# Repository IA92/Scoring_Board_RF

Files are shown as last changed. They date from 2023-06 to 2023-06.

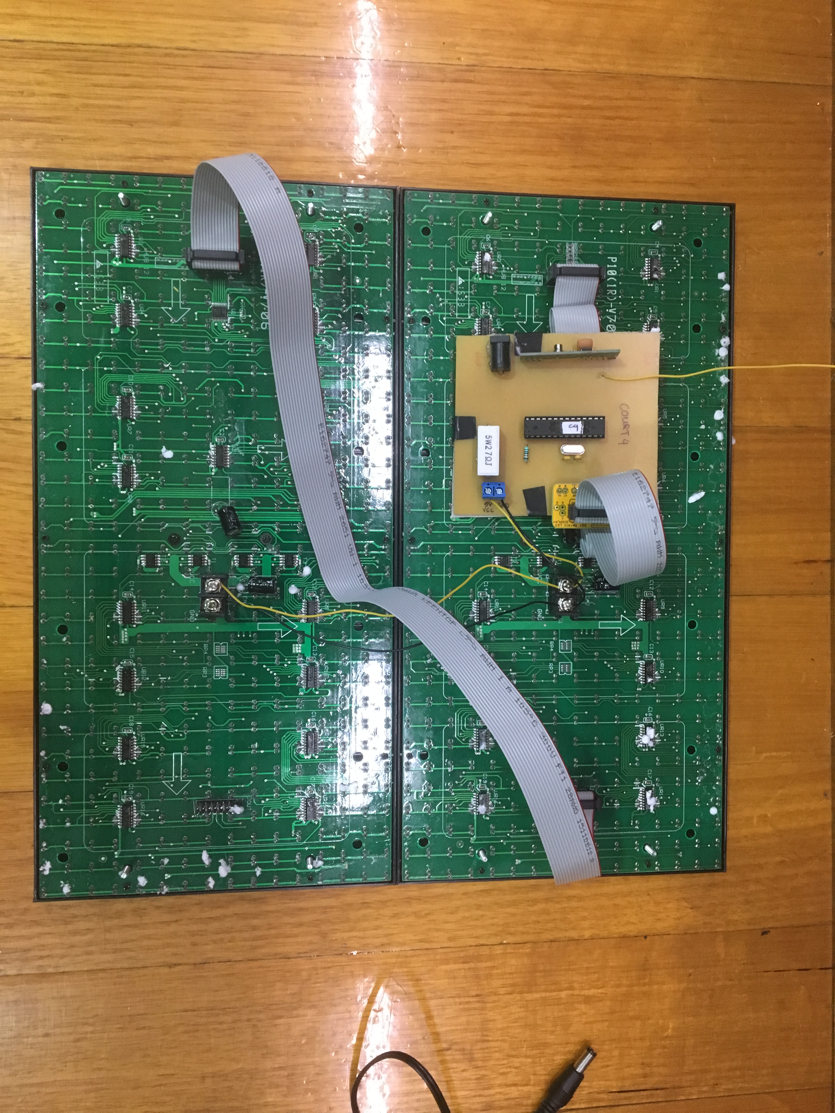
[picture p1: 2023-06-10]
photos/IMG_0790.JPG

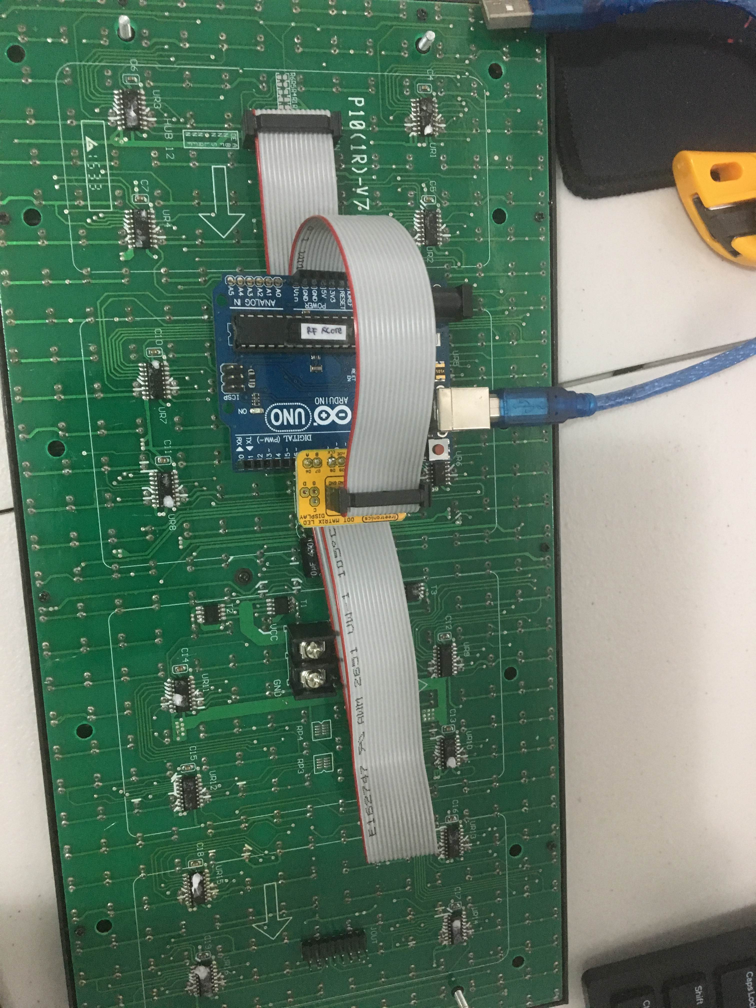
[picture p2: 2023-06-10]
photos/IMG_0505.JPG

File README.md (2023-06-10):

# Scoring_Board_RF
An archive of old scoring board project for badminton games.
Note: Code are not well written and managed. Instructions are not fully accurate.

Link to project video: https://youtu.be/4vFphWg7GTI

## Version of arduino files
- scoringBoard.ino: Testing LED panel
- scoringIR.ino, scoringIR_1 and scoringIR_2: 1 LED panel with IR instructions
- HunterBadminton_ProjectRF: 1 LED panel with RF instructions
- HunterBadminton_ProjectRF_Larger: 2 LED panel with RF instructions

## Getting Started with the Project RF Version
### Keyfob
- Get 433MHz key fobs from ebay.
- Use a 433MHz transmitter to transmit the desired code to be cloned by the key fob
- Set the key fob to be in programming mode and clone the transmitted code for each button. 
  - Reference video: https://www.youtube.com/watch?v=l-k_XvkZ0jE
### Code
- Ensure that `buttonCodes` array corresponds to the programmed instructions of the 4 buttons in the key fob

## References for the code in the libraries
- Freetronics lib https://github.com/freetronics/DMD/blob/master/DMD.cpp
- TimerOne lib http://code.google.com/p/arduino-timerone/downloads/list
- RF lib https://github.com/sui77/rc-switch/blob/master/RCSwitch.h

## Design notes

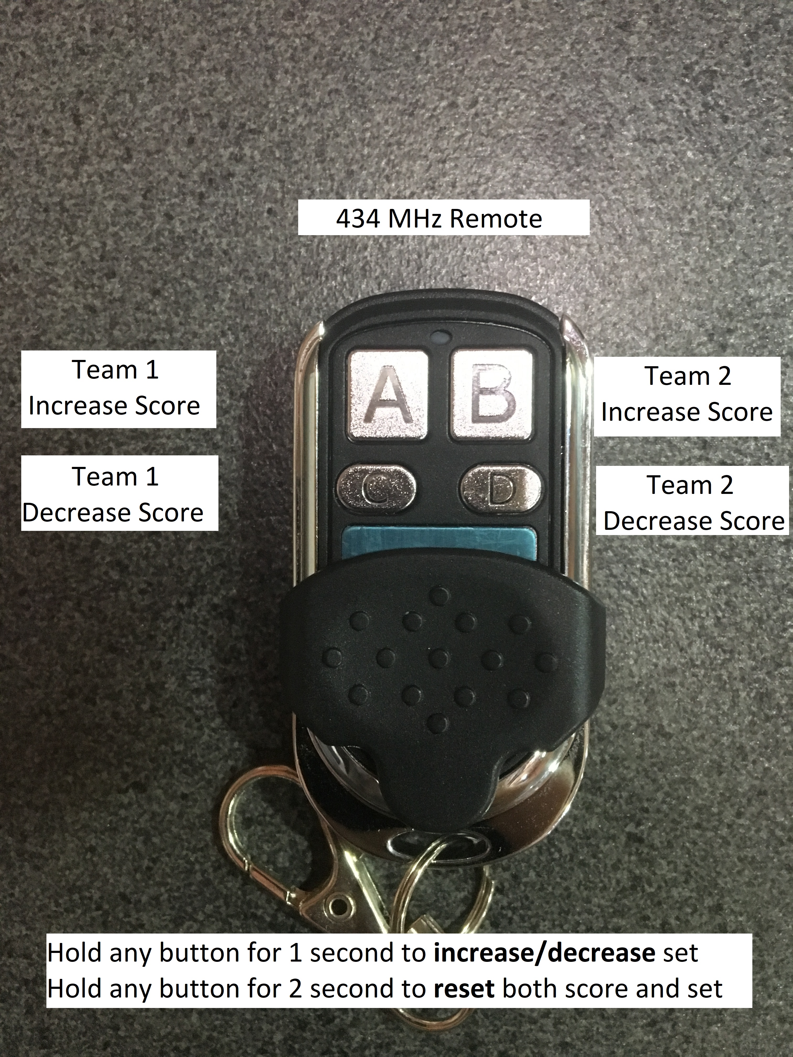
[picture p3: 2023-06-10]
photos/IMG_0797_Editted.JPG

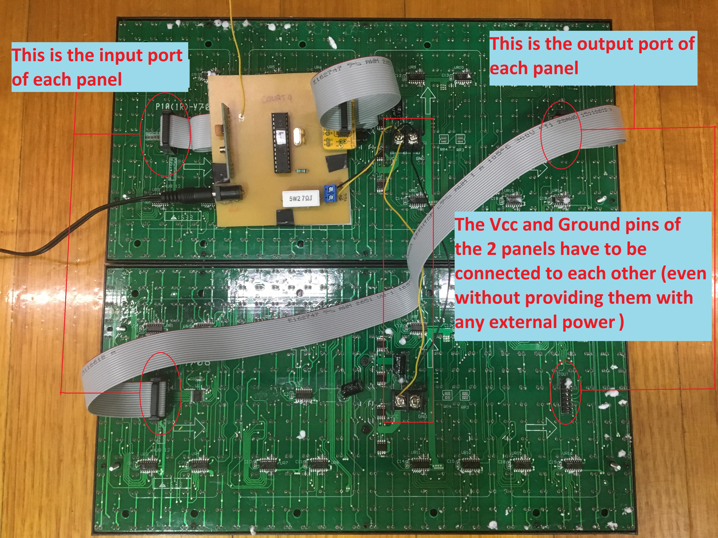
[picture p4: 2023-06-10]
photos/IMG_0792_editted.jpg

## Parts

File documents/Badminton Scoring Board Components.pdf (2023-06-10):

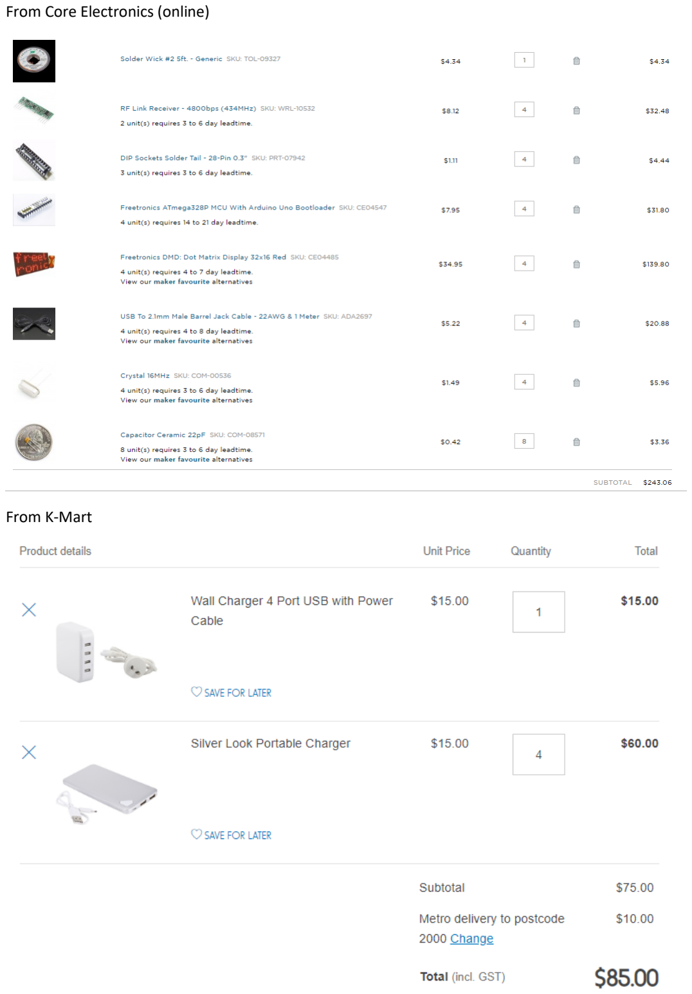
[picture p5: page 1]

From Core Electronics (online)

From K-Mart

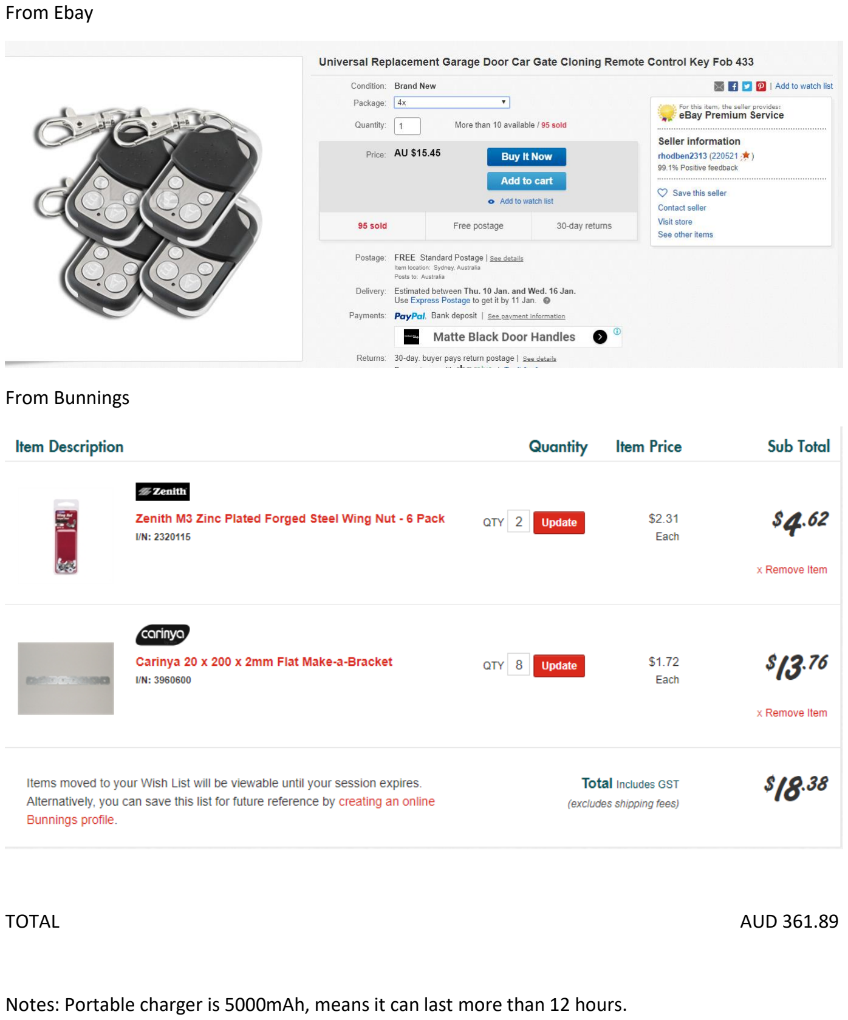
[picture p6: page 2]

From Ebay

From Bunnings

TOTAL | AUD 361.89

Notes: Portable charger is 5000mAh, means it can last more than 12 hours.

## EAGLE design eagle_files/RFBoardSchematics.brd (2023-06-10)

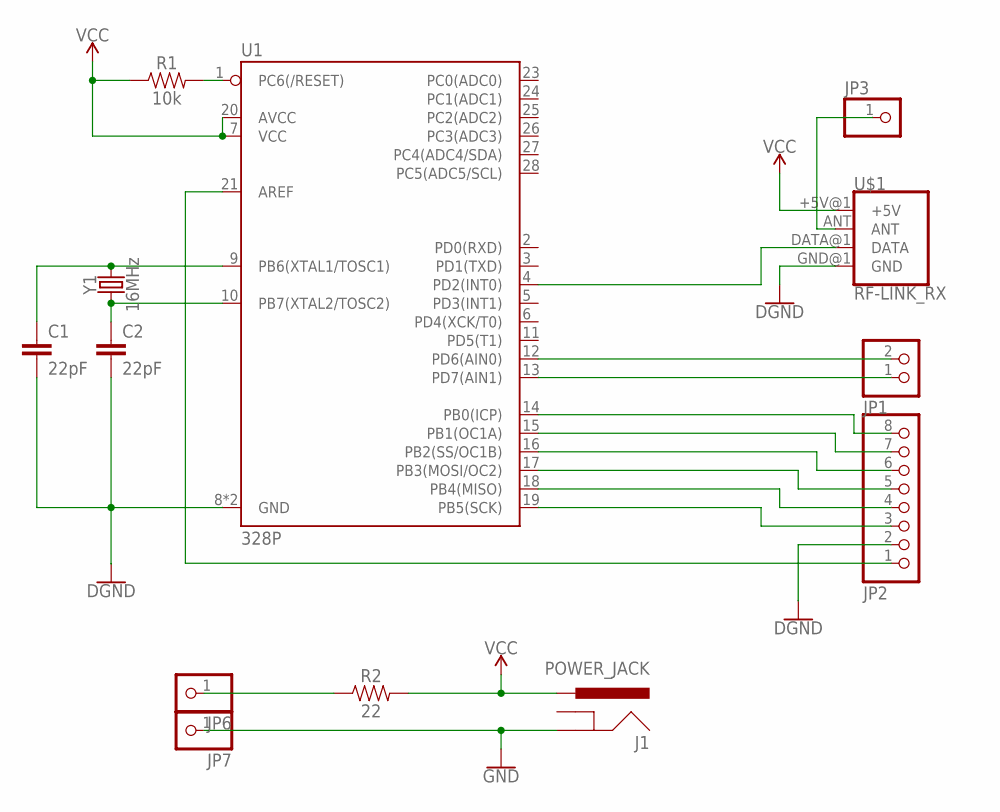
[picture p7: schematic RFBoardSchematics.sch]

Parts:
C1, C2: 22pF; CAP-PTH-2.54
J1: POWER_JACK; POWER_JACK_PTH
JP1: PINHD-1X2; 1X02
JP2: PINHD-1X8; 1X08
JP3, JP6, JP7: PINHD-1X1; 1X01
R1: 10k; AXIAL-0.3
R2: 22; AXIAL-0.3
U1: 328P; DIP28
U$1: RF-LINK_RX
Y1: 16MHz; HC49US

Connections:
GND: C1.2, C2.2, J1.GND, JP2.2, JP7.1, U1.8 (GND), U1.22 (GND), U$1.GND@1 (GND)
unnamed: R1.P$2 (2), U1.1 (PC6(/RESET))
unnamed: C1.1, U1.9 (PB6(XTAL1/TOSC1)), Y1.2
unnamed: C2.1, U1.10 (PB7(XTAL2/TOSC2)), Y1.1
unnamed: JP6.1, R2.P$1 (1)
unnamed: JP3.1, U$1.ANT
unnamed: U1.4 (PD2(INT0)), U$1.DATA@1 (DATA)
unnamed: JP1.2, U1.12 (PD6(AIN0))
unnamed: JP1.1, U1.13 (PD7(AIN1))
unnamed: JP2.8, U1.14 (PB0(ICP))
unnamed: JP2.7, U1.15 (PB1(OC1A))
unnamed: JP2.6, U1.16 (PB2(SS/OC1B))
unnamed: JP2.5, U1.17 (PB3(MOSI/OC2))
unnamed: JP2.4, U1.18 (PB4(MISO))
unnamed: JP2.3, U1.19 (PB5(SCK))
unnamed: JP2.1, U1.21 (AREF)
VCC: J1.PWR, R1.P$1 (1), R2.P$2 (2), U1.7 (VCC), U1.20 (AVCC), U$1.+5V@1 (+5V)

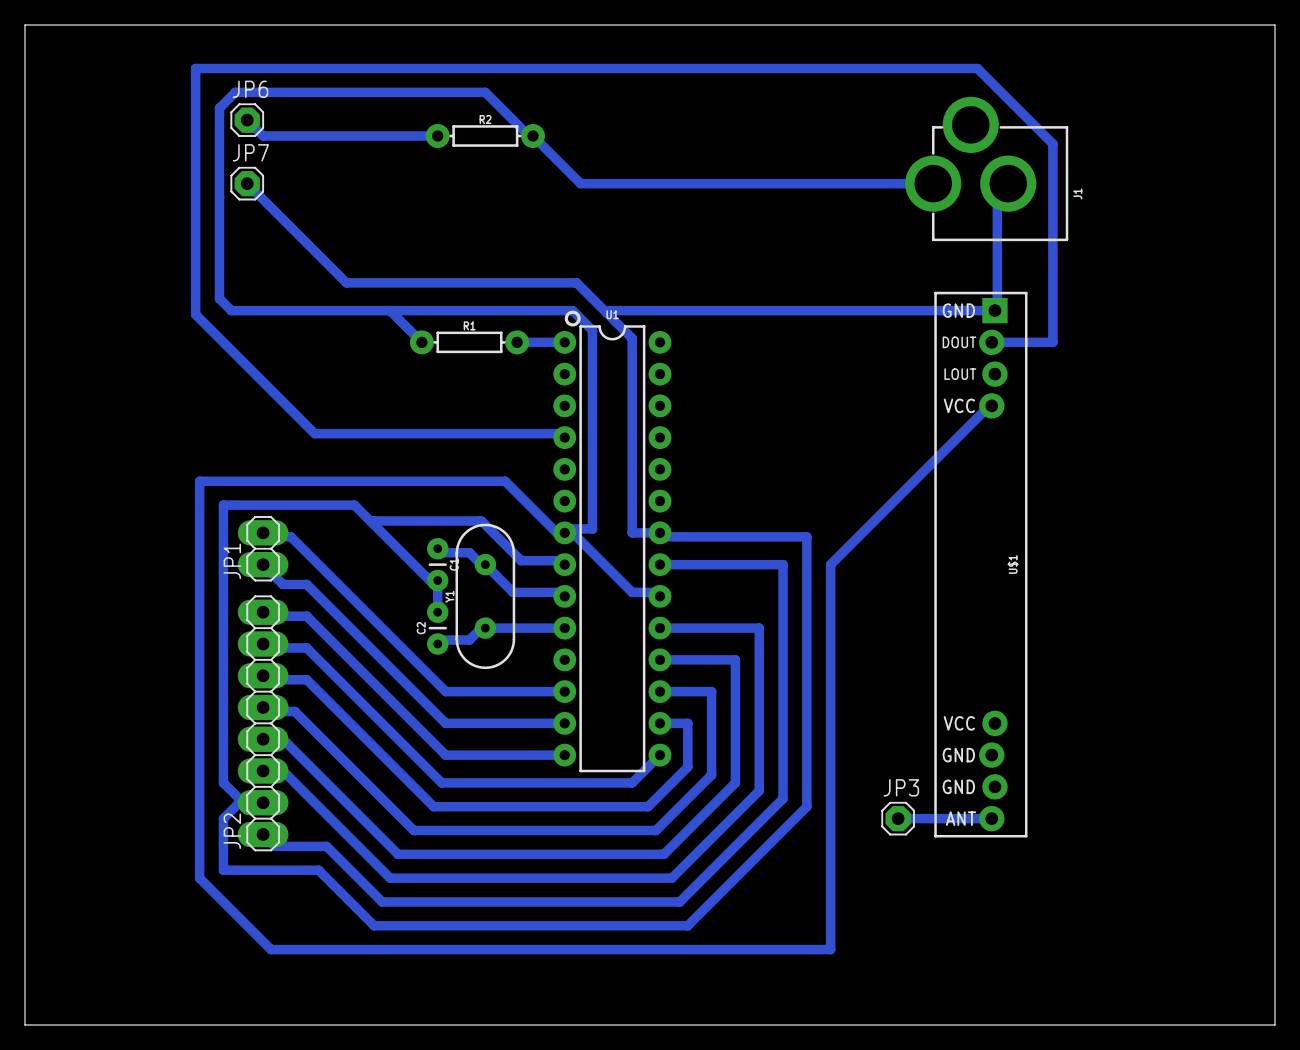
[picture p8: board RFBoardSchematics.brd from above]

Board: 2 copper layers, 100.0 x 80.0 mm, 13 parts (0 on the bottom side), 17 nets.

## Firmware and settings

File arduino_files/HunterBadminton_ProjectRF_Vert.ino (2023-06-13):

//Badminton Score Board with Team Serving
#include <SPI.h>        //SPI.h must be included as DMD is written by SPI (the IDE complains otherwise)
#include "DMD.h"        //
#include "TimerOne.h"   //
#include "SystemFont5x7.h"
#include "fixednums7x15.h"
#include "Arial_black_16.h"

#include "RCSwitch.h"

RCSwitch mySwitch = RCSwitch();

//Fire up the DMD library as dmd
#define DISPLAYS_ACROSS 1
#define DISPLAYS_DOWN 2
DMD dmd(DISPLAYS_ACROSS, DISPLAYS_DOWN);

int led=13;
String currentButton;
String secondButton;
String buttonCodes[]={"3001","3002","3003","3004"};
int countPress;
long int timePress;
int setA;char setAbuff[8];
int setB;char setBbuff[8];
char scoreA;char scoreAbuff[8];
char scoreB;char scoreBbuff[8];
int scoreX=17;
int scoreX_s=25;
int scoreYA=0;
int scoreYB=16;
int setX=12;
int setYA=3;
int setYB=19;
int serve;
bool toggle;
void ScanDMD()
{ 
  dmd.scanDisplayBySPI();
}
void clearPixels(int column_start, int column_end, int row_start, int row_end){
  for (int j=column_start;j<column_end;j++){   //Column
    for (int i=row_start;i<row_end;i++){  //Row
      dmd.writePixel(  j,i, GRAPHICS_NORMAL,0);
    }
  }
}
void drawServe(int Team){
  clearPixels(17, 32, 30, 32);
  clearPixels(17, 32, 14, 16);
  dmd.drawFilledBox(  17, (Team-1)*2+Team*14,31,(Team-1)*2+Team*14+1,GRAPHICS_NORMAL );
}

void drawSet(int setA, int setB){
  dmd.selectFont(SystemFont5x7);      
  if (setA==1) 
    dmd.drawChar(  setX,  setYA,  '1', GRAPHICS_NORMAL );
  else
    clearPixels(setX, scoreX, setYA, 14);
    
  if (setB==1) 
    dmd.drawChar(  setX,  setYB,  '1', GRAPHICS_NORMAL );
  else
    clearPixels(setX, scoreX, setYB, 28);
}

void drawScore(int8_t scoreAtemp, int8_t scoreBtemp){
  dmd.selectFont(fixednums7x15);
  if (scoreAtemp<10){
    dmd.drawString(  scoreX,  scoreYA, "0", 2, GRAPHICS_NORMAL );
    dmd.drawString(  scoreX_s,  scoreYA, itoa (scoreAtemp, scoreAbuff, 10), 2, GRAPHICS_NORMAL );
  } else{
    dmd.drawString(  scoreX,  scoreYA, itoa (scoreAtemp, scoreAbuff, 10), 2, GRAPHICS_NORMAL );
  }
  
  if (scoreBtemp<10){
    dmd.drawString(  scoreX, scoreYB, "0", 2, GRAPHICS_NORMAL );
    dmd.drawString(  scoreX_s, scoreYB, itoa (scoreBtemp, scoreBbuff, 10), 2, GRAPHICS_NORMAL );
  } else{
    dmd.drawString(  scoreX, scoreYB, itoa (scoreBtemp, scoreBbuff, 10), 2, GRAPHICS_NORMAL );
  }
}

void setup() {
  Serial.begin(9600);
  mySwitch.enableReceive(0); 
  delay(2000); while (!Serial); //delay for Leonardo
  pinMode(led, OUTPUT);
  Serial.println(F("Ready to receive RF signals"));
  
     //initialize TimerOne's interrupt/CPU usage used to scan and refresh the display
   Timer1.initialize( 5000 );           //period in microseconds to call ScanDMD. Anything longer than 5000 (5ms) and you can see flicker.
   Timer1.attachInterrupt( ScanDMD );   //attach the Timer1 interrupt to ScanDMD which goes to dmd.scanDisplayBySPI()
  
  // Initiating Variable
  setA=0;
  setB=0;
  scoreA=0;
  scoreB=0;
  serve=1;
  toggle=false;
  countPress=0;
  currentButton="1000";
  secondButton="1000";
  //clear/init the DMD pixels held in RAM
  dmd.clearScreen( true );   //true is normal (all pixels off), false is negative (all pixels on)
  //initializing
  dmd.selectFont(SystemFont5x7);   
  dmd.drawString(  0,  scoreYA,  "SE", 2, GRAPHICS_NORMAL );
  dmd.drawString(  0,  scoreYA+8,  "AT", 2, GRAPHICS_NORMAL );
  dmd.drawString(  0,  scoreYB,  "WA", 2, GRAPHICS_NORMAL );
  dmd.drawString(  0,  scoreYB+8,  "LL", 2, GRAPHICS_NORMAL );
  drawSet(setA, setB);
   drawScore(scoreA, scoreB);
//   dmd.drawFilledBox(17,14,31,15,GRAPHICS_NORMAL);
   drawServe(serve);
}
 
void loop() {

  byte b;
  //Continue looping until you get a complete signal received
  if (millis()-timePress>100){
      countPress=0;
    }
  if (mySwitch.available()) {
    secondButton=String(mySwitch.getReceivedValue());
    if (secondButton==currentButton && ((millis()-timePress)<100||countPress==1)){
      countPress=countPress+1;
      mySwitch.resetAvailable();
      Serial.println(currentButton);
      Serial.println(secondButton);
      if (countPress==5){
        if (currentButton==buttonCodes[3]){
          setB=setB-1;
          Serial.println("SetB-");
        }
        else if (currentButton==buttonCodes[1]){
          if (setA+setB<3) setB=setB+1;
          Serial.println("SetB+");
          serve=2;
          toggle=true;
        }
        else if (currentButton==buttonCodes[2]){
          setA=setA-1;
          Serial.println("SetA-");
        }
        else if (currentButton==buttonCodes[0]){
          if (setA+setB<3) setA=setA+1;
          Serial.println("SetA+");
          serve=1;
          toggle=false;
        }
        if (scoreA<0) scoreA=0;
        else if (scoreA>31) scoreA=31;
        if (scoreB<0) scoreB=0;
        else if (scoreB>31) scoreB=31;      
        if (setA<0) setA=0; 
        if (setA>2) setA=2;
        if (setB<0) setB=0; 
        if (setB>2) setB=2;
        drawScore(scoreA, scoreB);
        drawServe(serve);
        if (serve>2) {
          serve=1;
          drawServe(serve);
        } else if (serve<1){
          serve=2;
          drawServe(serve);
        }
        mySwitch.resetAvailable();
        drawSet(setA, setB);
      }
      else if (countPress==10){
        toggle = toggle? false : true;
        serve = serve + 1;
        int tempA = scoreA;
        scoreA=scoreB;
        scoreB=tempA;
        setA = 0;
        setB = 0;
        drawScore(scoreA, scoreB);
        drawServe(serve);
        if (serve>2) {
          serve=1;
          drawServe(serve);
        } else if (serve<1){
          serve=2;
          drawServe(serve);
        }
        mySwitch.resetAvailable();
        drawSet(setA, setB);
      }
      else if (countPress==20){
      Serial.println("in countpress>25");
//      if ((currentButton==buttonCodes[0] || currentButton==buttonCodes[1]) && (secondButton==buttonCodes[2] || secondButton==buttonCodes[3]) ){
        setA=0;
        setB=0;
        scoreA=0;
        scoreB=0;
        toggle=false;
        serve=1;
//      }
        if (scoreA<0) scoreA=0;
        else if (scoreA>31) scoreA=31;
        if (scoreB<0) scoreB=0;
        else if (scoreB>31) scoreB=31;      
        if (setA<0) setA=0; 
        if (setA>2) setA=2;
        if (setB<0) setB=0; 
        if (setB>2) setB=2;
        drawScore(scoreA, scoreB);
        drawServe(serve);
        if (serve>2) {
          serve=1;
          drawServe(serve);
        } else if (serve<1){
          serve=2;
          drawServe(serve);
        }
        countPress=0;
        mySwitch.resetAvailable();
        drawSet(setA, setB);
    }
    }
    
    
    else if (countPress<5){
      currentButton=secondButton;
      countPress=1;
      if (currentButton!=buttonCodes[9] && currentButton!="0"){
        
        if (currentButton==buttonCodes[0]){
          scoreA=scoreA+1;
          if (toggle){
            serve=serve+1;
//            drawServe(serve);
            toggle=false;
          }
          Serial.println("ScoreA+");
        }
        else if (currentButton==buttonCodes[2]){
          scoreA=scoreA-1;
          Serial.println("ScoreA-");
        }
        else if (currentButton==buttonCodes[1]){
          scoreB=scoreB+1;
          if (!toggle){
            serve=serve+1;
//            drawServe(serve);
            toggle=true;
          }
          Serial.println("scoreB+");
        }
        else if (currentButton==buttonCodes[3]){
          scoreB=scoreB-1;
          Serial.println("scoreB-");
        }
        if (scoreA<0) scoreA=0;
        else if (scoreA>31) scoreA=31;
        if (scoreB<0) scoreB=0;
        else if (scoreB>31) scoreB=31;      
        if (setA<0) setA=0; 
        if (setA>2) setA=2;
        if (setB<0) setB=0; 
        if (setB>2) setB=2;
        drawScore(scoreA, scoreB);
        drawServe(serve);
        if (serve>2) {
          serve=1;
          drawServe(serve);
        } else if (serve<1){
          serve=2;
          drawServe(serve);
        }
        mySwitch.resetAvailable();
        drawSet(setA, setB);
      }
    }
    timePress=millis();
    }
  
}

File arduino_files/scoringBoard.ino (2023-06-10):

/*--------------------------------------------------------------------------------------

 dmd_test.cpp 
   Demo and example project for the Freetronics DMD, a 512 LED matrix display
   panel arranged in a 32 x 16 layout.

 Copyright (C) 2011 Marc Alexander (info <at> freetronics <dot> com)

 See http://www.freetronics.com/dmd for resources and a getting started guide.

 Note that the DMD library uses the SPI port for the fastest, low overhead writing to the
 display. Keep an eye on conflicts if there are any other devices running from the same
 SPI port, and that the chip select on those devices is correctly set to be inactive
 when the DMD is being written to.

 USAGE NOTES
 -----------

 - Place the DMD library folder into the "arduino/libraries/" folder of your Arduino installation.
 - Get the TimerOne library from here: http://code.google.com/p/arduino-timerone/downloads/list
   or download the local copy from the DMD library page (which may be older but was used for this creation)
   and place the TimerOne library folder into the "arduino/libraries/" folder of your Arduino installation.
 - Restart the IDE.
 - In the Arduino IDE, you can open File > Examples > DMD > dmd_demo, or dmd_clock_readout, and get it
   running straight away!

 * The DMD comes with a pre-made data cable and DMDCON connector board so you can plug-and-play straight
   into any regular size Arduino Board (Uno, Freetronics Eleven, EtherTen, USBDroid, etc)
  
 * Please note that the Mega boards have SPI on different pins, so this library does not currently support
   the DMDCON connector board for direct connection to Mega's, please jumper the DMDCON pins to the
   matching SPI pins on the other header on the Mega boards.

 This example code is in the public domain.
 The DMD library is open source (GPL), for more see DMD.cpp and DMD.h

--------------------------------------------------------------------------------------*/

/*--------------------------------------------------------------------------------------
  Includes
--------------------------------------------------------------------------------------*/
#include <SPI.h>        //SPI.h must be included as DMD is written by SPI (the IDE complains otherwise)
#include <DMD.h>        //
#include <TimerOne.h>   //
#include "SystemFont5x7.h"
#include "Arial_black_16.h"
#include "Droid_Sans_12.h"

//Fire up the DMD library as dmd
#define DISPLAYS_ACROSS 1
#define DISPLAYS_DOWN 1
DMD dmd(DISPLAYS_ACROSS, DISPLAYS_DOWN);

/*--------------------------------------------------------------------------------------
  Interrupt handler for Timer1 (TimerOne) driven DMD refresh scanning, this gets
  called at the period set in Timer1.initialize();
--------------------------------------------------------------------------------------*/
void ScanDMD()
{ 
  dmd.scanDisplayBySPI();
}

/*--------------------------------------------------------------------------------------
  setup
  Called by the Arduino architecture before the main loop begins
--------------------------------------------------------------------------------------*/
void setup(void)
{

   //initialize TimerOne's interrupt/CPU usage used to scan and refresh the display
   Timer1.initialize( 5000 );           //period in microseconds to call ScanDMD. Anything longer than 5000 (5ms) and you can see flicker.
   Timer1.attachInterrupt( ScanDMD );   //attach the Timer1 interrupt to ScanDMD which goes to dmd.scanDisplayBySPI()

   //clear/init the DMD pixels held in RAM
   dmd.clearScreen( true );   //true is normal (all pixels off), false is negative (all pixels on)

}

/*--------------------------------------------------------------------------------------
  loop
  Arduino architecture main loop
--------------------------------------------------------------------------------------*/
void loop(void)
{
   byte b;
   
   // 10 x 14 font clock, including demo of OR and NOR modes for pixels so that the flashing colon can be overlayed
   dmd.clearScreen( true );
   dmd.selectFont(System5x7);
   dmd.drawString(  5,  0, "1", 1, GRAPHICS_NORMAL );
   dmd.drawString(  22,  0, "01", 1, GRAPHICS_NORMAL );
//   dmd.selectFont(Droid_Sans_12);
   int scoreX=3;
   int scoreXm=18;
   int scoreY=9;
   dmd.drawString(  scoreX,  scoreY, "12", 2, GRAPHICS_NORMAL );
   dmd.drawString(  scoreXm, scoreY, "34", 2, GRAPHICS_NORMAL );
   delay( 8000 );  
   dmd.drawString(  scoreX,  scoreY, "56", 2, GRAPHICS_NORMAL );
   dmd.drawString(  scoreXm, scoreY, "78", 2, GRAPHICS_NORMAL );  
   delay( 8000 );  
   dmd.drawString(  scoreX,  scoreY, "90", 2, GRAPHICS_NORMAL );
   dmd.drawString(  scoreXm, scoreY, "10", 2, GRAPHICS_NORMAL ); 
   delay( 8000 );    
   
}

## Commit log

2023-06-10 Add all arduino files
2023-06-10 Add eagle schematic and board files.
    [RFBoardSchematics.brd, RFBoardSchematics.sch]
2023-06-10 Add IRLibAll.h
    It is used in scoringIR arduino files where IR transmitter is used to send the instructions.
2023-06-13 Fix bug with unclearing the set when it is 0.
    [HunterBadminton_ProjectRF_Vert.ino]
2023-06-13 Fix serve bug. Adjust display.
    [HunterBadminton_ProjectRF_Vert.ino]
2023-06-13 Shorten the hold time.
    [HunterBadminton_ProjectRF_Vert.ino]

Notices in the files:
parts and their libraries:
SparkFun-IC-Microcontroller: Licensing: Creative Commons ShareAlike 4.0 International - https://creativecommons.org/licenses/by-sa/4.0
